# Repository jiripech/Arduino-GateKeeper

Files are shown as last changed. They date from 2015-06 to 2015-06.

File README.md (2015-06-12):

# Arduino-GateKeeper
Arduino Nano project to control two servo motors which are pushing two remote controller
buttons controlling two car gates. Nano is connected through the USB port to a machine
where the simple PHP web app is used to control two gates from your phone instead of using
the remote controller itself.

The thing is that you probably don't want to destroy your remote controller when doing such
a stuff, so you basically put it into a 3D printed holder where it stays until the battery
is gone or you just don't need it anymore.

Application must have access to /dev/ttyUSBx where it reads from and writes to. This is
configured in the gatekeeper.php file.

Two M6 screws with nuts are needed to put the 3D printed holders together.
Feel free to modify it, so it suits your needs.

# Directories and files
_Gatekeeper_ directory holds the Arduino files.

_gatekeeper.php_ is an example PHP application controlling the servos. You have to post a button to it and it expects an authentication.

_Holder.scad_ is the OpenSCAD source.

_Holder_V.stl_ is the vertical part of the holder.

_Holder_H.stl_ is the horizontal part of the holder.

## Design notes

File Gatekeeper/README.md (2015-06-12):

# Arduino GateKeeper project.

Servos are turned against each other, so they have a slightly different turn angles. Also
both servos are detached after they are used to avoid any unnecessary energy consumption.

Servos are wired to Arduino GND (black), 5V (red) and pins 7 (servo 1 yellow)
and 9 (servo 2 yellow). This can be configured in gate1pin and gate2pin respectively.

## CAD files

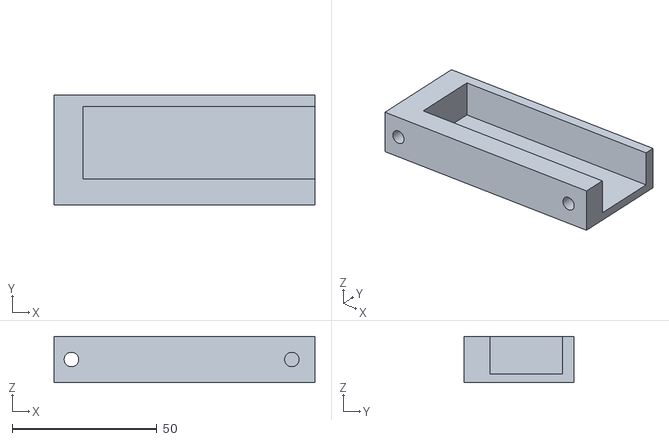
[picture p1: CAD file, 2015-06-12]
Holder_H.stl
90.0 x 38.0 x 16.0

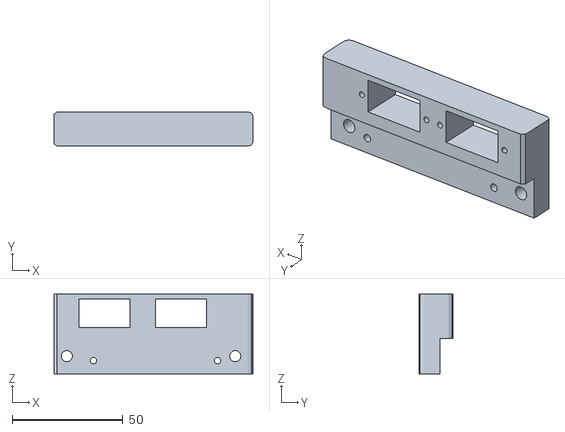
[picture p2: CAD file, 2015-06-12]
Holder_V.stl
89.8 x 15.4 x 36.0

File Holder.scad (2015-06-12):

module roundedRect(size, radius) {
  x = size[0];
  y = size[1];
  z = size[2];

  linear_extrude(height=z)
  hull() {
    translate([radius, radius, 0])
      circle(r=radius);

    translate([x - radius, radius, 0])
      circle(r=radius);

    translate([x - radius, y - radius, 0])
      circle(r=radius);

    translate([radius, y - radius, 0])
      circle(r=radius);
  }
}

module remote_buttons(lem = 0) {
  btn_r_I    =  5;
  btn_r_O    =  btn_r_I + 5;

  difference() {
    cylinder(r = btn_r_O + lem, h = 1);
    translate([0, 0, -0.5]) cylinder(r = btn_r_I - lem, h = 2);
    translate([0, -lem, 0]) rotate([0, 0, -135]) cube([10, 10, 10]);
    translate([0, +lem, 0]) rotate([0, 0, +45]) cube([10, 10, 10]);
  }  
}

module remote_box() {
  dim_Y = 25;
  dim_X = 100;
  dim_Z = 14;
    
  cube([dim_X, dim_Y, dim_Z]);
}

module remote() {
  dim_Y = 25;
  dim_X = 60;
  dim_Z = 14;
    
  // some logo on the remote
  int_btn_X = 40;
  int_btn_L = 10;
  int_btn_W =  8;
  int_btn_H =  1.5;
    
  // a notch on the remote
  cb_dim_X = 10;
  cb_dim_W = 20;
  cb_dim_L = 28;
  cb_dim_H =  1;
    
  btn_center = 24;
 
  difference() {
    union () {
      cube([dim_X, dim_Y, dim_Z]);
      translate([int_btn_X, (dim_Y - int_btn_W) / 2, dim_Z])
        roundedRect([int_btn_L, int_btn_W, int_btn_H], 1);
    }
    translate([cb_dim_X, (dim_Y - cb_dim_W) / 2, dim_Z - cb_dim_H])
      cube([cb_dim_L, cb_dim_W, cb_dim_H * 2]); 
 
    translate([btn_center, dim_Y / 2, dim_Z - 2 * cb_dim_H])
      remote_buttons(0.8);
  }

  translate([btn_center, dim_Y / 2, dim_Z - 2 * cb_dim_H])
    remote_buttons();
}

module lever(rotated = 0) {
  cen_R = 6.5 / 2;
  cen_H = 4.5;
    
  lev_H = 1.5;
  lev_R = 1.45;
    
  lev_L = 19.75;
  hle_R = 0.25;

  sml_R = 2.5;
  sml_X = cen_H - 3;

  rotate([rotated + 90, 0, 90]) difference() {
    union() {
      rotate([0, -90, 0]) cylinder(r = cen_R, h = cen_H, $fn = 72);
 
      hull() {
        rotate([0, -90, 0]) cylinder(r = cen_R, h = lev_H, $fn = 72);
        translate([0, 0, lev_L - cen_R - lev_R])
          rotate([0, -90, 0]) cylinder(r = lev_R, h = lev_H, $fn = 72);
      }
    }
    for (i = [0:5]) {
        translate([lev_H, 0, lev_L - cen_R - lev_R - i * ((lev_L - cen_R - lev_R) / 7)])
         rotate([0, -90, 0]) cylinder(r = hle_R, h = lev_H * 3, $fn = 72);      
    }
    translate([-sml_X, 0, 0]) rotate([0, -90, 0]) cylinder(r = sml_R, h = cen_H, $fn = 72);
    translate([sml_X, 0, 0]) rotate([0, -90, 0]) cylinder(r = lev_R, h = cen_H, $fn = 72);
  }
}

module servo_holes() {
  srv_X = 23;
  srv_Y = 24;
  srv_Z = 12;
    
  hld_X = 16;
  hld_L =  2.5;
  hld_W = 32.5;
    
  sml_X = 11.5;
  sml_R = 2.5;
  rod_R = 2.25 / 2;
    
  translate([(srv_X - hld_W) / 2, hld_X, 0]) {
    translate([2, -3 * hld_L, srv_Z / 2])
      rotate([-90, 0, 0])
        cylinder(r = rod_R, h = hld_L * 5, $fn = 72);
    translate([hld_W - 2, -3 * hld_L, srv_Z / 2])
      rotate([-90, 0, 0])
        cylinder(r = rod_R, h = hld_L * 5, $fn = 72);
  }
}
module servo(lever_rotated = 0) {
  srv_X = 23;
  srv_Y = 25;
  srv_Z = 12.75;
 
  hld_X = 16;
  hld_L =  2.5;
  hld_W = 32.5;
    
  sml_X = 11.5;
  sml_R = 2.5;
  rod_R = 2.25 / 2;
 
  rod_L = 31;
  cen_L = 27.5;
 
  cube([srv_X, srv_Y, srv_Z]);
  difference() {
    translate([(srv_X - hld_W) / 2, hld_X, 0])
      cube([hld_W, hld_L, srv_Z]);
    servo_holes();
  }
  translate([srv_Z / 2, 0, srv_Z / 2])
    rotate([-90, 0, 0]) {
      cylinder(r = sml_R, h = rod_L, $fn = 72);
      cylinder(r = srv_Z / 2, h = cen_L, $fn = 72);
    }

  translate([sml_X, 0, srv_Z / 2])
    rotate([-90, 0, 0])
      cylinder(r = sml_R, h = cen_L, $fn = 72);
    
  translate([srv_Z / 2, rod_L, srv_Z / 2])
    lever(rotated = lever_rotated);
}

module holder_holes() {
  translate([-4, -50, 5])
    rotate([-90, 0, 0]) cylinder(r = 2.5, h = 100, $fn = 72);
  translate([72, -30, 5])
    rotate([-90, 0, 0]) cylinder(r = 2.5, h = 35, $fn = 72);
  translate([8, -30, 3])
    rotate([-90, 0, 0]) cylinder(r = 1.45, h = 25, $fn = 72);
  translate([64, -30, 3])
    rotate([-90, 0, 0]) cylinder(r = 1.45, h = 25, $fn = 72);
}

module holder_boxes() {
  translate([0, 5, 0]) remote_box();
  translate([1.5, -20, 18]) {
    servo(45);
    servo_holes();
  }
  translate([+36, -20, 18]) {
    servo(-225);
    servo_holes();
  }
}

module holder_show() {
  translate([0, 5, 0]) remote();
  translate([1.5, -20, 18]) servo(45);
  translate([+36, -20, 18]) servo(-225);
}

out_dim_X = -10;
out_dim_Y = 34 - out_dim_X;
out_dim_L = 90;
out_dim_Z = 16;

module holder_H() {
  difference() {
    difference() {
        translate([-10, out_dim_X, -3]) cube([out_dim_L, out_dim_Y, out_dim_Z]);
        translate([-10, -19.5, -3]) cube([90, 15.5, 36]);
        holder_holes();
    }
    holder_boxes();
  }
}

module holder_V() {    
  difference() {
    difference() {
        translate([-10, -19.5, -3]) roundedRect([90, 15.5, 36], 2);
        translate([-10, out_dim_X, -3]) cube([out_dim_L, out_dim_Y, out_dim_Z]);
        holder_holes();
    }
    holder_boxes();
  }
}

holder_V();
holder_H();

// holder_show();

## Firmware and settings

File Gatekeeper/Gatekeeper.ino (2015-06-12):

#include <Servo.h> 
 
Servo G1;
Servo G2;
 
int gate1pin = 9;
int gate2pin = 7;

int pos = 90;
int incomingByte = 0;

String crlf = "\n";

void setup() { 
  Serial.begin(9600);
  G1.attach(gate1pin);
  G2.attach(gate2pin);
  G1.write(120);
  delay(100);
  G2.write(50);
  delay(100);
  Serial.print("Ready");
  delay(100);
  G1.detach();
  G2.detach();
} 

void openGate(int gateNo) {
  if (gateNo == 1) {
    G1.attach(gate1pin);
    delay(10);
    for(pos = 120; pos <= 180; pos += 1) {
      G1.write(pos);
      delay(round(pos / 100) + 1);
    }
    delay(1000);
    for(pos = 180; pos >= 120; pos -= 1) {
      G1.write(pos);
      delay(round(pos / 100) + 1);
    }
    delay(50);
    G1.detach();
  }

  if (gateNo == 2) {
    G2.attach(gate2pin);
    delay(10);
    for(pos = 50; pos >= 0; pos -= 1) {
      G2.write(pos);
      delay(round((pos) / 100) + 1);
    }
    delay(1000);
    for(pos = 0; pos <= 50; pos += 1) {
      G2.write(pos);
      delay(round((pos) / 100) + 1);
    }
    delay(50);
    G2.detach();
  }
}
 
void loop() { 
  if (Serial.available() > 0) {
    incomingByte = Serial.read();
    if ((incomingByte == 49) || (incomingByte == 1)) {
      Serial.print("Gate 1" + crlf);
      openGate(1);
    }
    if ((incomingByte == 50) || (incomingByte == 2)) {
      Serial.print("Gate 2" + crlf);
      openGate(2);
    }
  }
}
